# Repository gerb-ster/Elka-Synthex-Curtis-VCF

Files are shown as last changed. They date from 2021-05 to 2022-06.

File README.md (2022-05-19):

# Elka Synthex 'Curtis' VCF

A clone of the VCF found in the Elka Synthex around the CEM 3320 IC. This project is still 'work in progress', a
prototype has been build, but it's not quite bug free. 

_the current design needs to be debugged_

## Status: Work in Progress

- done: first schematic & board design
- done: breadboard and test
- done: design frontpanel
- done: order PCB 
- todo: build (working) prototype

## Links

https://bitbucket.org/XNOTOX/synthex-vcf/src/master/ 
https://electricdruid.net/cem3320-filter-designs/ 
https://www.instructables.com/How-to-Program-an-Attiny85-From-an-Arduino-Uno/

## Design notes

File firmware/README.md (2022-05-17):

# Elka Synthex 'Curtis' VCF firmware

The mode selection is done using a push button and a bunch of ADG412 chips 
and a Atmel ATtiny25/45/85. This directory contains a .ino file with some arduino
code. This needs to be rewritten to proper AVR-C code in a platform.io project.

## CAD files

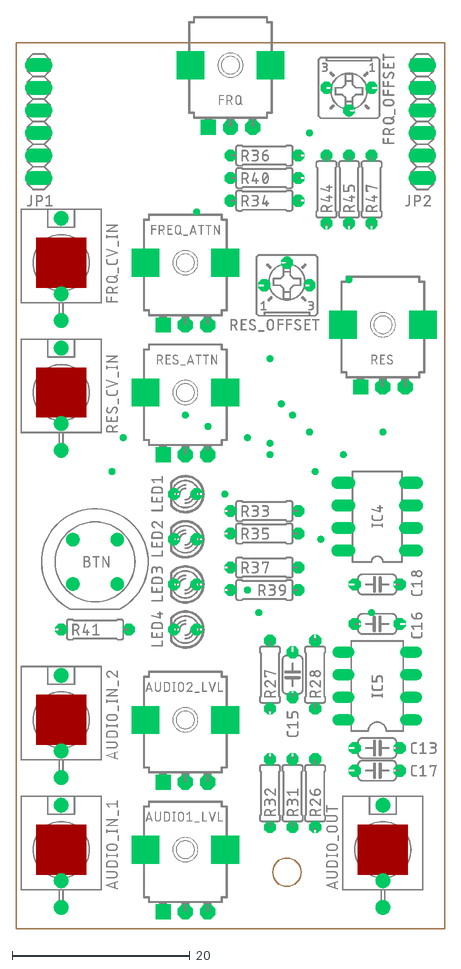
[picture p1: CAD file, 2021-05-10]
faceplates/Elka Synthex Full.dxf
48.3 x 102.7

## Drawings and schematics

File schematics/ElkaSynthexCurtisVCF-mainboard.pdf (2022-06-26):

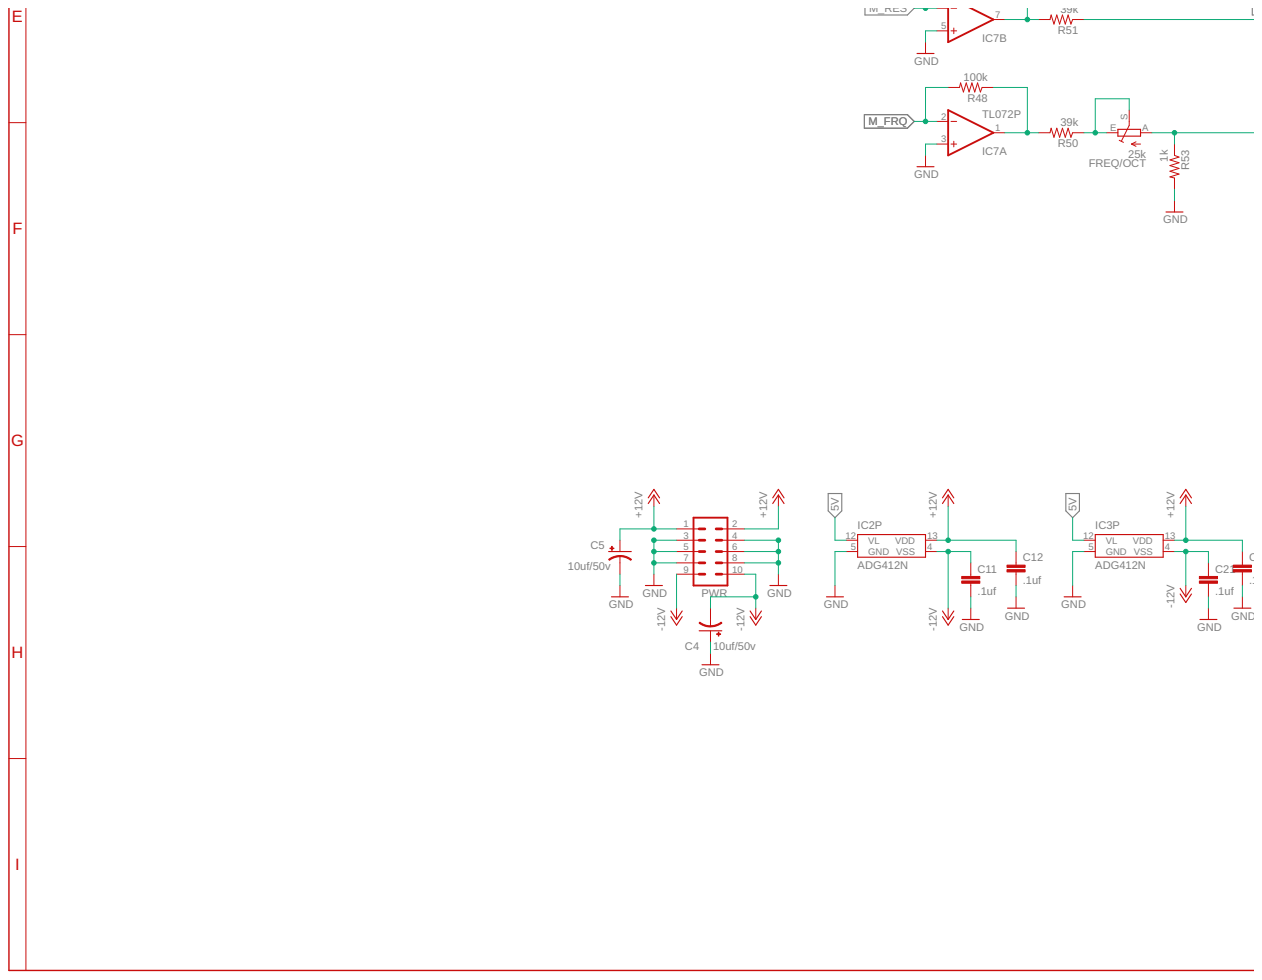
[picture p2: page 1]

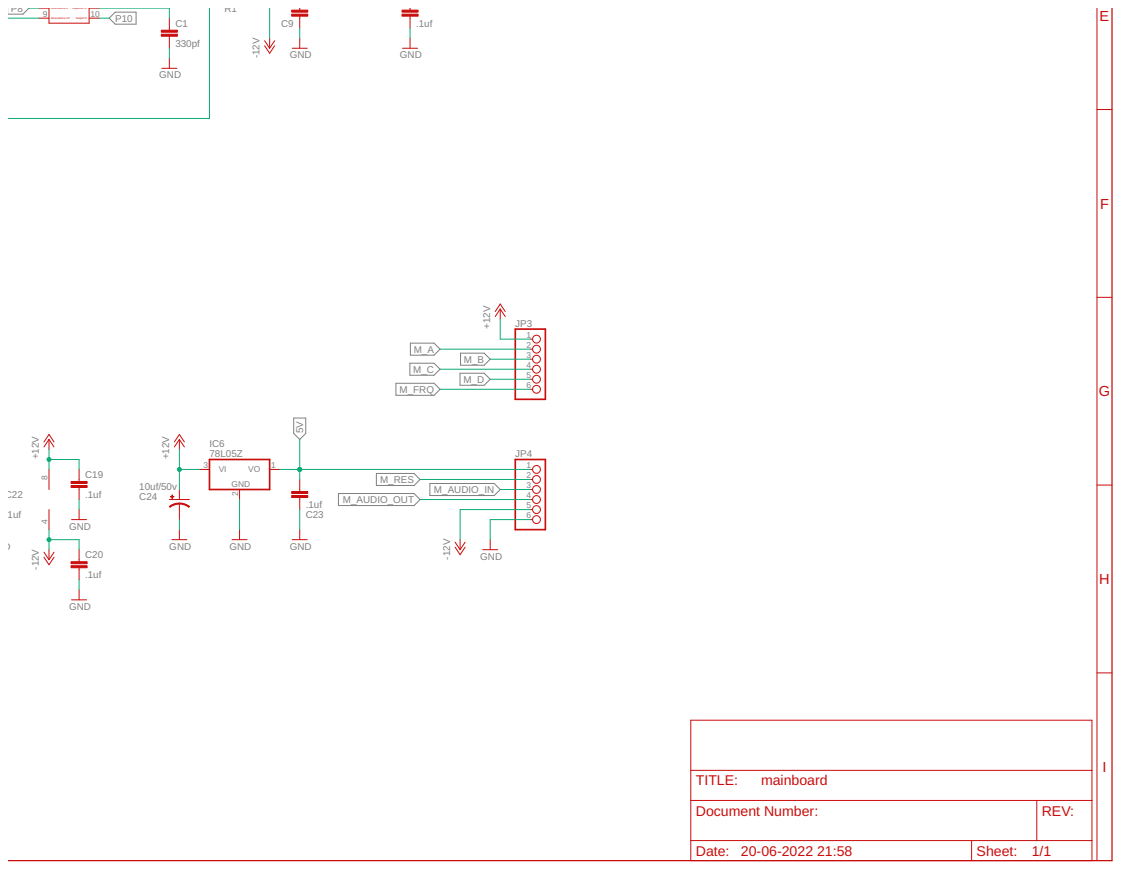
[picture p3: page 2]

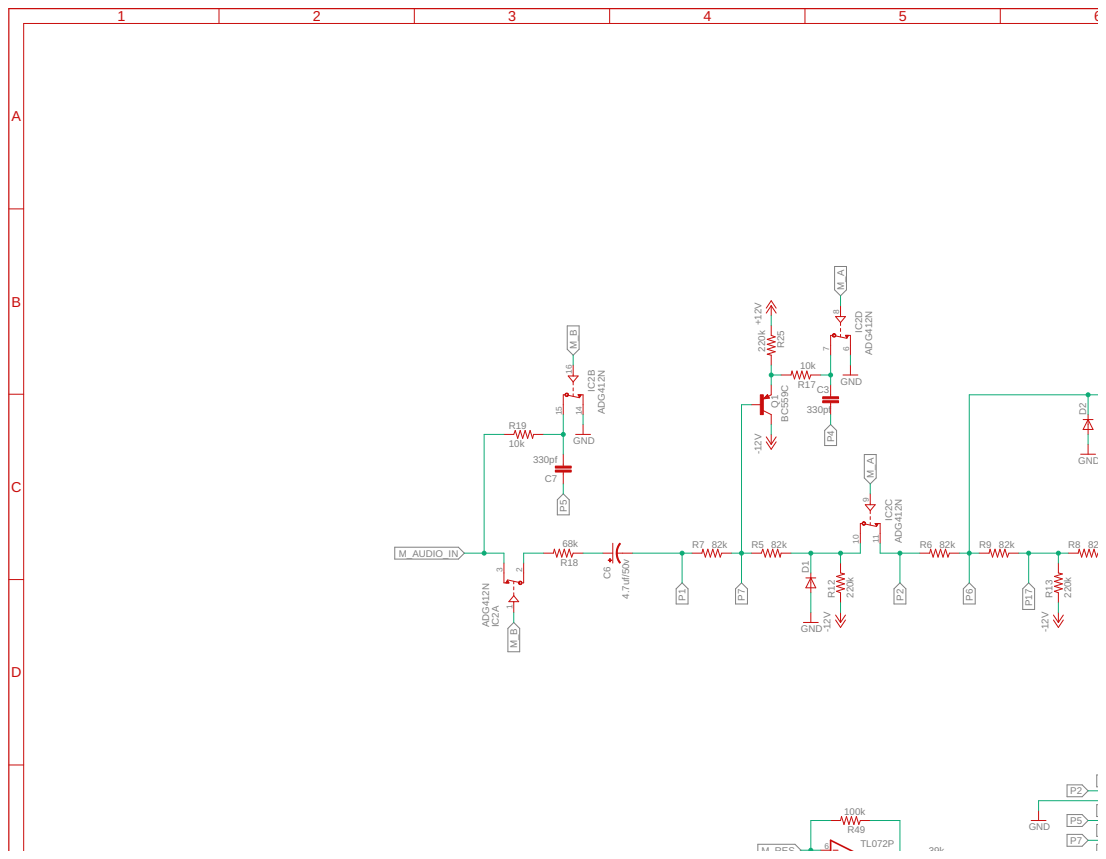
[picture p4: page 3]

+12V -12V 82k 82k 82k 82k 82 220k -12V 220k -12V GND BC559C 10k330pf GND 4.7uf/50v 68k 330pf 10k GND GND 220k GND TL072P 100k 39k ADG412N ADG412N ADG412N ADG412N R7 R5 R6 R9 R8 R12 R13 D1 Q1 R17C3 C6R18 C7 R19 D2 R25 6 R49 1 32 IC2A 16 1415 IC2B 9 1110 IC2C 8 76 IC2D M_RES M_AUDIO_IN M_A M_A M_B M_B P17 P1 P5 P5 P7 P7 P2 P2 P6 P4 ABCD 1 2 3 4 5 6

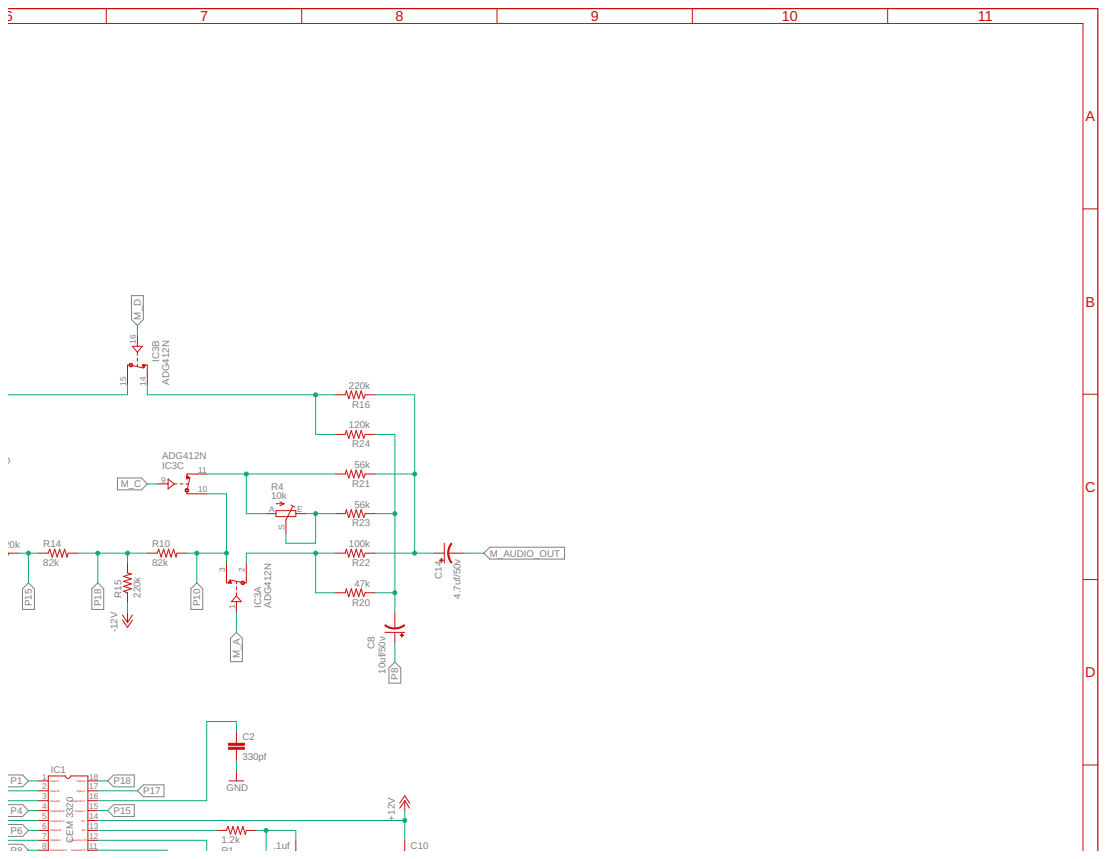
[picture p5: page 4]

+12V -12V 1.2k 330pf GND 10k 82k 82k 82k 82k 820k 82k 220k -12V 220k -12V 82k 220k -12V GND BC559C220k +12V 10k330pf GND 4.7uf/50v 68k f GND 10uf/50v 47k 56k 100k 120k GND 220k 56k .1uf GND 4.7uf/50v CEM 3320 TL072P 100k 39k ADG412N ADG412N ADG412N ADG412N ADG412N ADG412N R1 C2 A E S R4 R7 R5 R6 R9 R8 R10 R12 R13 R14 R15 D1 Q1 R16 R17C3 C6R18 C8 R20 R21 R22 R24 D2 R25 R23 C10 C14 12345678 1112131415161718 IC1 6 R49 16 1415 IC2B 9 1110 IC2C 8 76 IC2D 1 32 IC3A 16 1415 IC3B 9 1110 IC3C M_RES M_C M_D M_AUDIO_OUT M_A M_A M_A M_B P17 P17 P1 P1 P5 P5 P7 P7 P2 P2 P6 P6 P15 P15 P18 P18 P10 P4 P4 P8 P8 Input A Input B Ground Capacitor B Capacitor A Output B Output A Resonance in Capacitor D Frequency ctrl Iee Vcc Output C Capacitor C Input C Input D ABCD 4 5 6 7 8 9 10 11

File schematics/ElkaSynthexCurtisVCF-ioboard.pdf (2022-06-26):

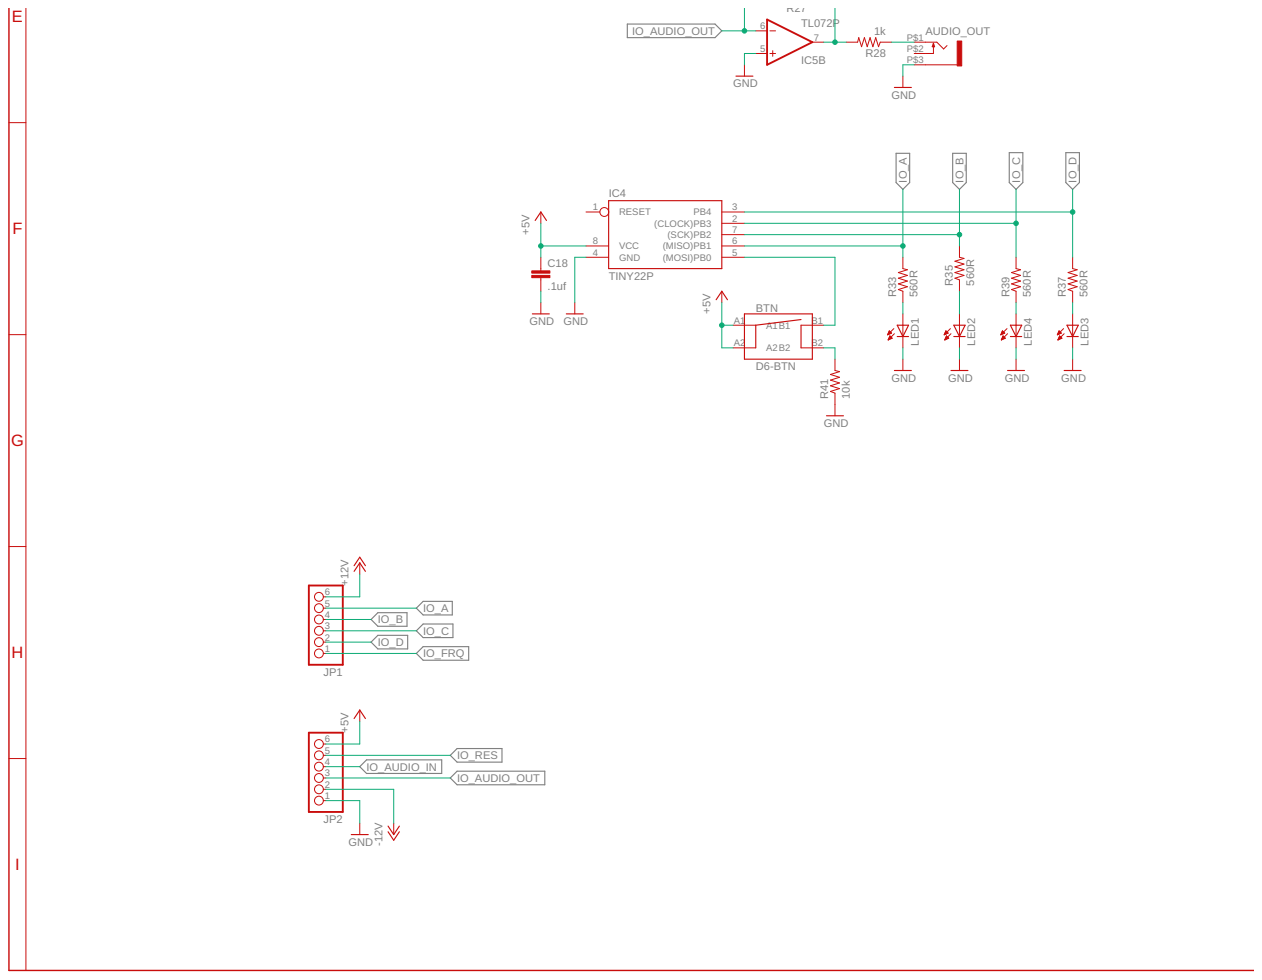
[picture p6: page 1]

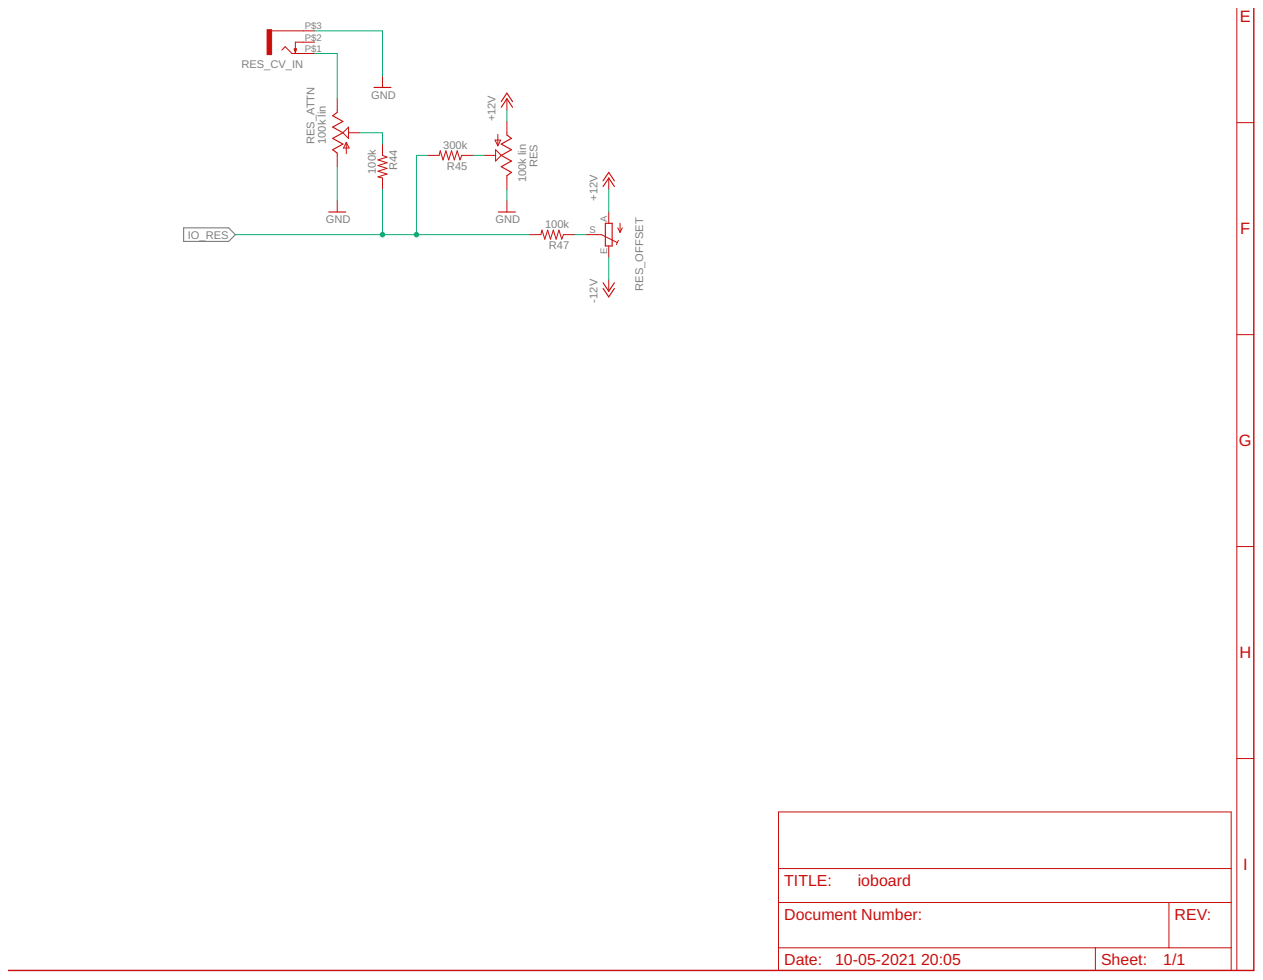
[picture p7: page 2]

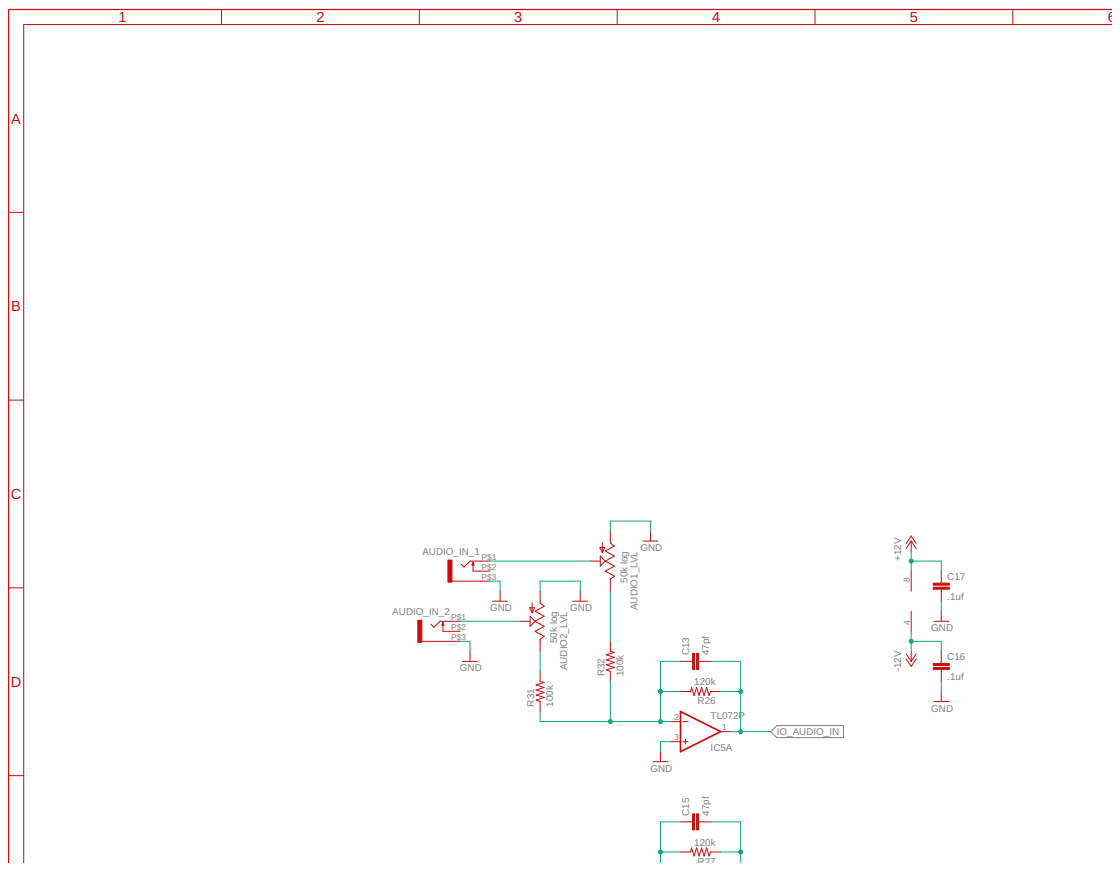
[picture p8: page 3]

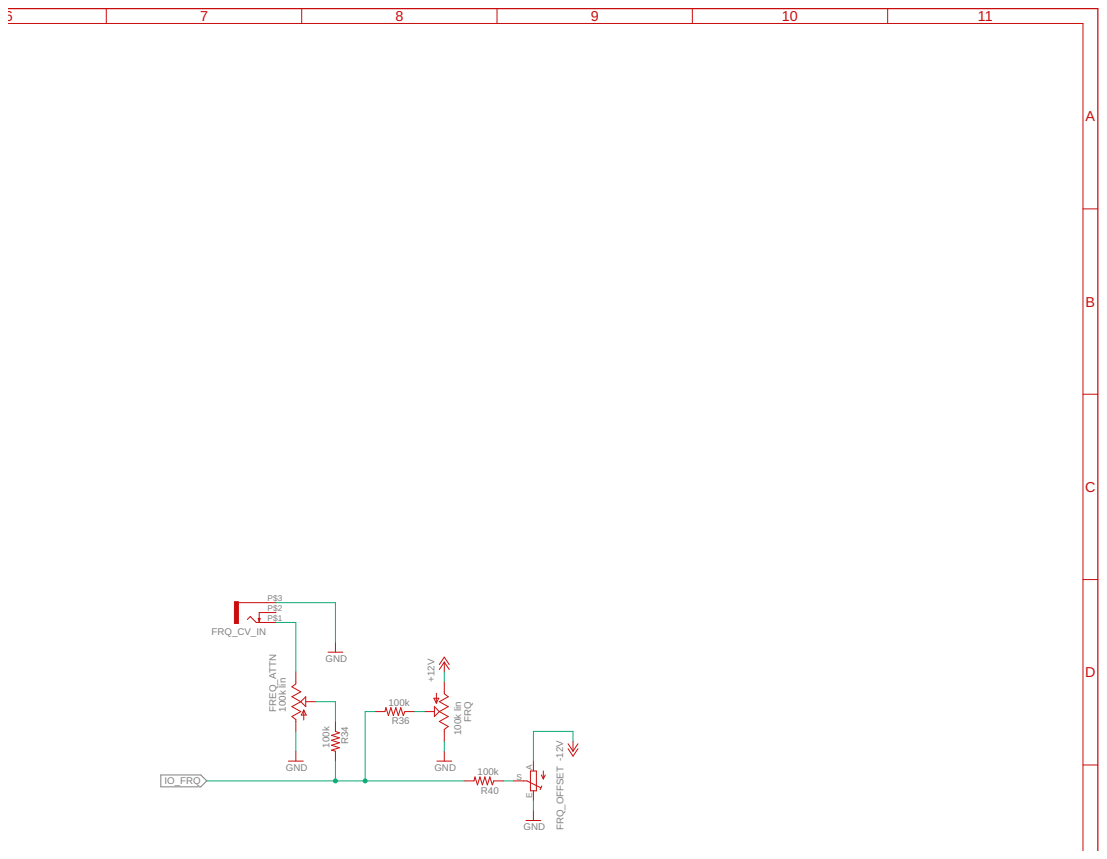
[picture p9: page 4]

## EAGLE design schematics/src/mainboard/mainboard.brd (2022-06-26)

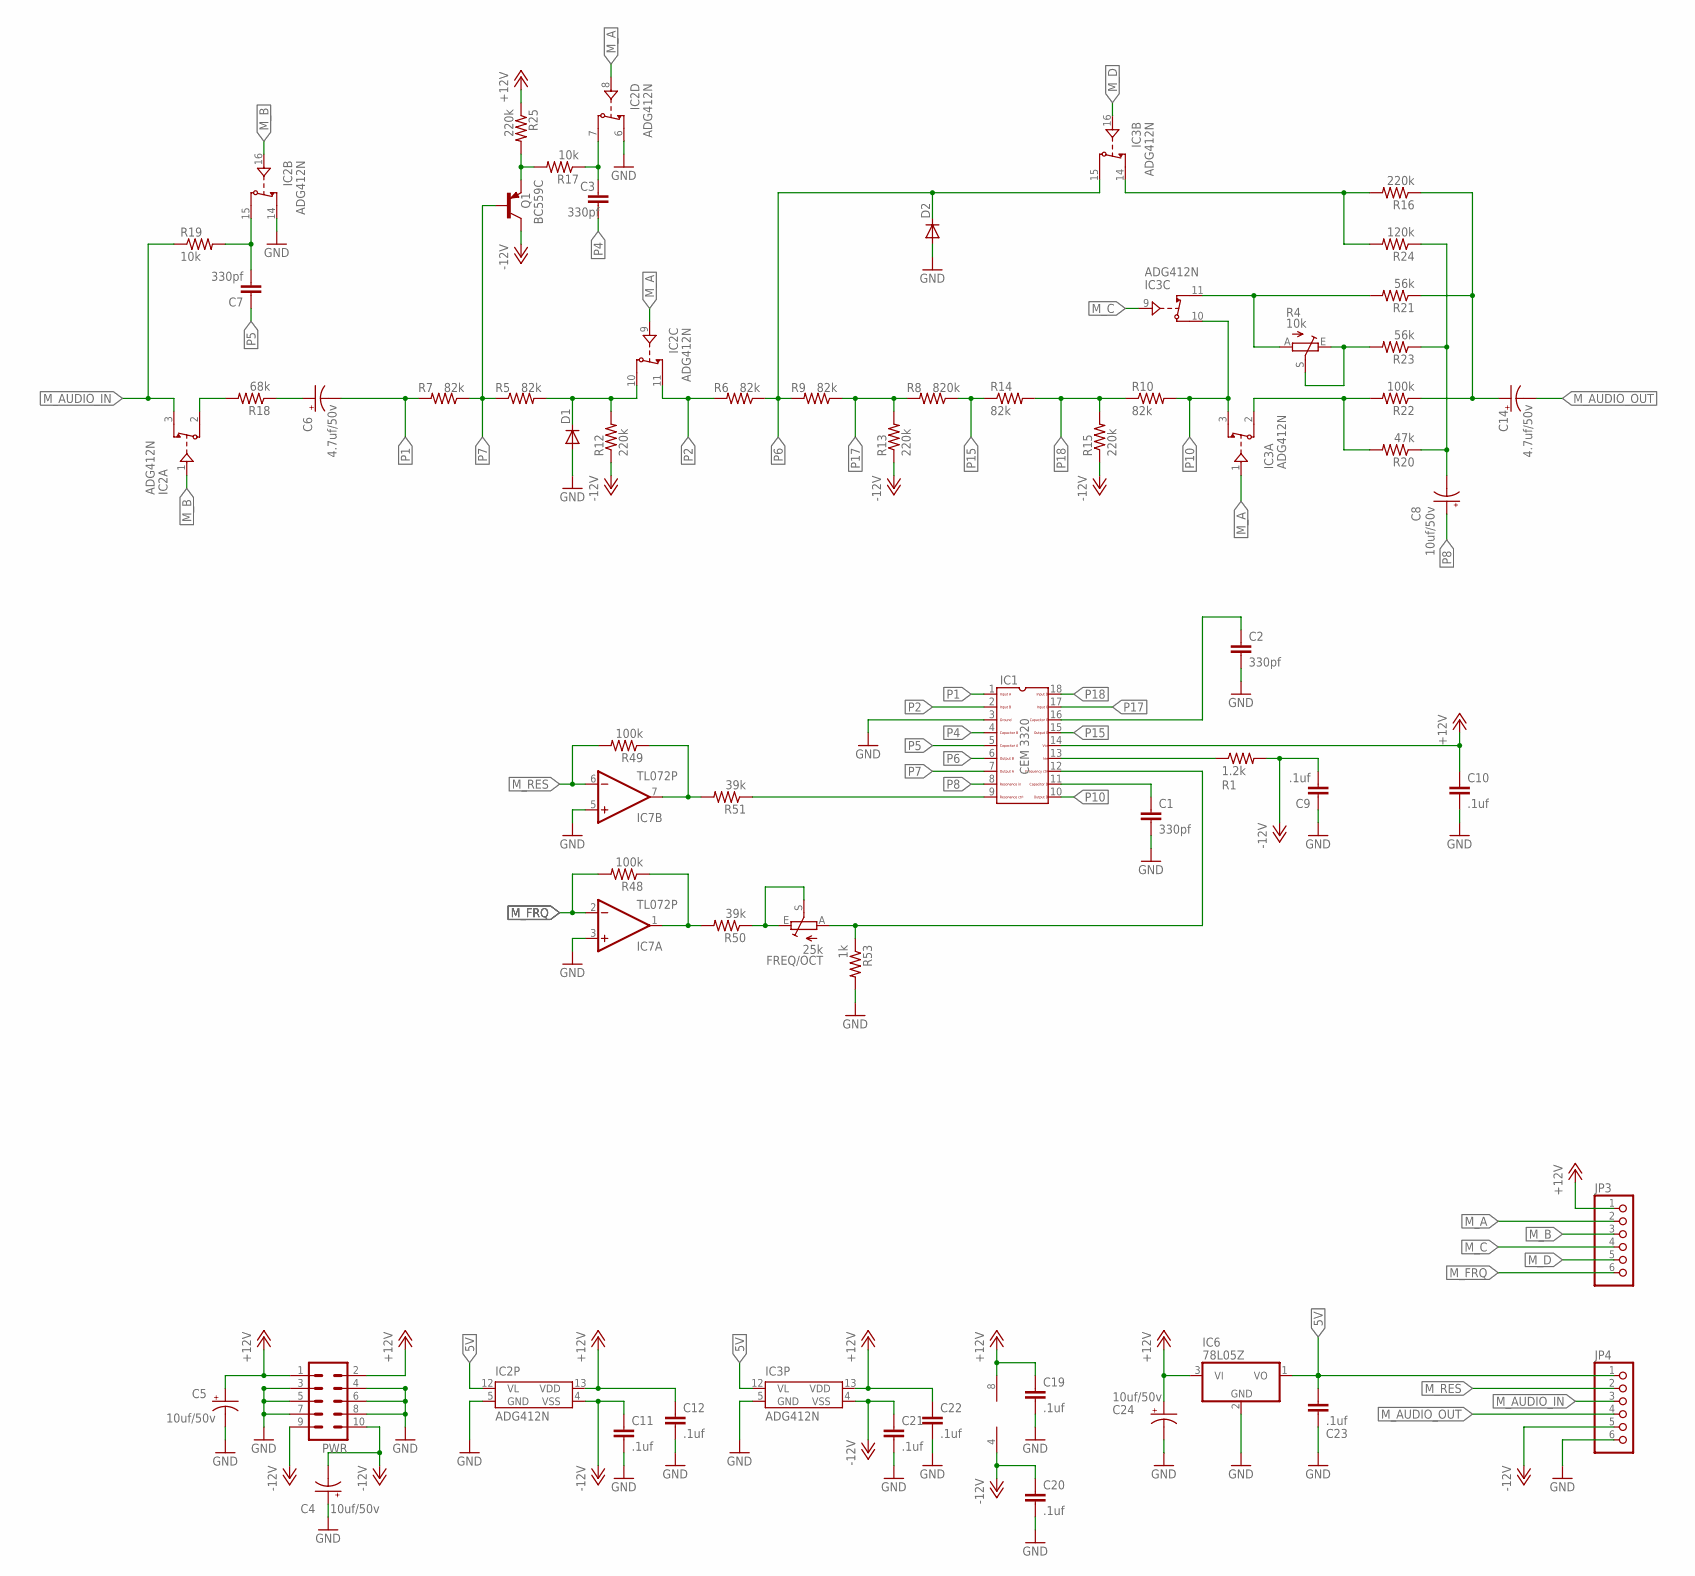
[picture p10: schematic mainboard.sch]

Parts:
C1, C2, C3, C7: 330pf; C050-050X075
C4, C5, C8, C24: 10uf/50v; E2,5-5
C6, C14: 4.7uf/50v; E2,5-5
C9, C10, C11, C12, C19, C20, C21, C22, C23: .1uf; C050-024X044
D1, D2: 1N4148DO35-7; DO35-7
FREQ/OCT: 25k; S64YW
IC1: CEM3320; DIL18
IC2, IC3: ADG412N; DIL16
IC6: 78L05Z; TO92
IC7: TL072P; DIL08
JP3, JP4: PINHD-1X6; 1X06
PWR: ML10
Q1: BC559C; TO92-EBC
R1: 1.2k; 0207/10
R4: 10k; S64YW
R5, R6, R7, R9, R10, R14: 82k; 0207/10
R8: 820k; 0207/10
R12, R13, R15, R16, R25: 220k; 0207/10
R17, R19: 10k; 0207/10
R18: 68k; 0207/10
R20: 47k; 0207/10
R21, R23: 56k; 0207/10
R22, R48, R49: 100k; 0207/10
R24: 120k; 0207/10
R50, R51: 39k; 0207/10
R53: 1k; 0207/10

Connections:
5V: C23.1, IC2.12 (VL), IC3.12 (VL), IC6.1 (VO), JP4.1
+12V: C5.+, C10.1, C12.1, C19.1, C22.1, C24.+, IC1.14, IC2.13 (VDD), IC3.13 (VDD), IC6.3 (VI), IC7.8 (V+), JP3.1, PWR.1, PWR.2, R25.1
-12V: C4.-, C9.2, C11.1, C20.1, C21.1, IC2.4 (VSS), IC3.4 (VSS), IC7.4 (V-), JP4.5, PWR.9, PWR.10, Q1.C, R1.2, R12.1, R13.1, R15.1
GND: C1.1, C2.2, C4.+, C5.-, C9.1, C10.2, C11.2, C12.2, C19.2, C20.2, C21.2, C22.2, C23.2, C24.-, D1.A, D2.A, IC1.3, IC2.5 (GND), IC2.6 (S), IC2.14 (S), IC3.5 (GND), IC6.2 (GND), IC7.3 (+IN), IC7.5 (+IN), JP4.6, PWR.3, PWR.4, PWR.5, PWR.6, PWR.7, PWR.8, R53.2
INT_FRQ: FREQ/OCT.A, IC1.12, R53.1
INT_RES: IC1.9, R51.1
M_A: IC2.8 (IN), IC2.9 (IN), IC3.1 (IN), JP3.2
M_AUDIO_IN: IC2.3 (S), JP4.3, R19.1
M_AUDIO_OUT: C14.-, JP4.4
M_B: IC2.1 (IN), IC2.16 (IN), JP3.3
M_C: IC3.9 (IN), JP3.4
M_D: IC3.16 (IN), JP3.5
M_FRQ: IC7.2 (-IN), JP3.6, R48.2
M_RES: IC7.6 (-IN), JP4.2, R49.2
unnamed: Q1.E, R17.2, R25.2
unnamed: C6.+, R18.1
unnamed: D1.C, IC2.10 (D), R5.2, R12.2
unnamed: IC3.2 (D), R20.2, R22.2
unnamed: IC2.2 (D), R18.2
unnamed: C7.2, IC2.15 (D), R19.2
unnamed: R4.E, R4.S, R23.2
unnamed: C3.1, IC2.7 (D), R17.1
unnamed: C14.+, R16.1, R21.1, R22.1
unnamed: IC3.11 (S), R4.A, R21.2
unnamed: IC3.14 (S), R16.2, R24.2
unnamed: C8.-, R20.1, R23.1, R24.1
unnamed: C2.1, IC1.16
unnamed: IC1.13, R1.1
unnamed: C1.2, IC1.11
unnamed: FREQ/OCT.E, FREQ/OCT.S, R50.1
unnamed: IC7.7 (OUT), R49.1, R51.2
unnamed: IC7.1 (OUT), R48.1, R50.2
P1: C6.-, IC1.1, R7.2
P2: IC1.2, IC2.11 (S), R6.2
P4: C3.2, IC1.4
P5: C7.1, IC1.5
P6: D2.C, IC1.6, IC3.15 (D), R6.1, R9.2
P7: IC1.7, Q1.B, R5.1, R7.1
P8: C8.+, IC1.8
P10: IC1.10, IC3.3 (S), IC3.10 (D), R10.2
P15: IC1.15, R8.1, R14.1
P17: IC1.17, R8.2, R9.1, R13.2
P18: IC1.18, R10.1, R14.2, R15.2

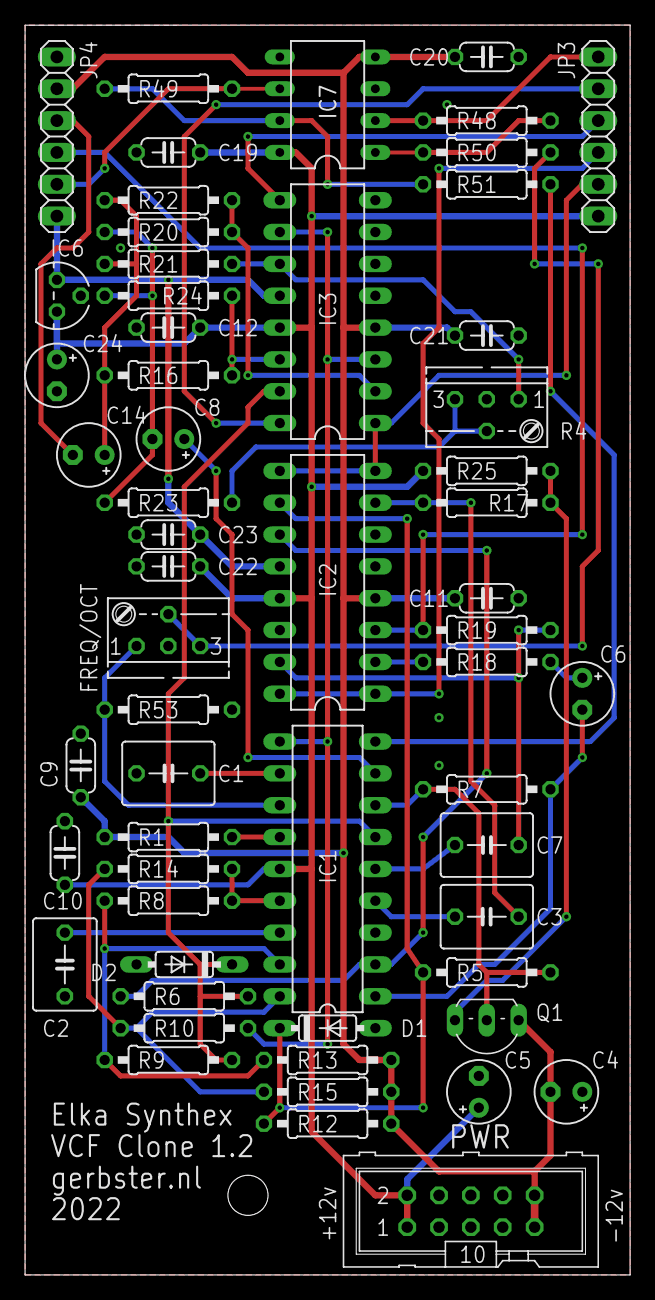
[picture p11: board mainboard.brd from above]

Board: 2 copper layers, 48.3 x 99.7 mm, 58 parts (0 on the bottom side), 43 nets.

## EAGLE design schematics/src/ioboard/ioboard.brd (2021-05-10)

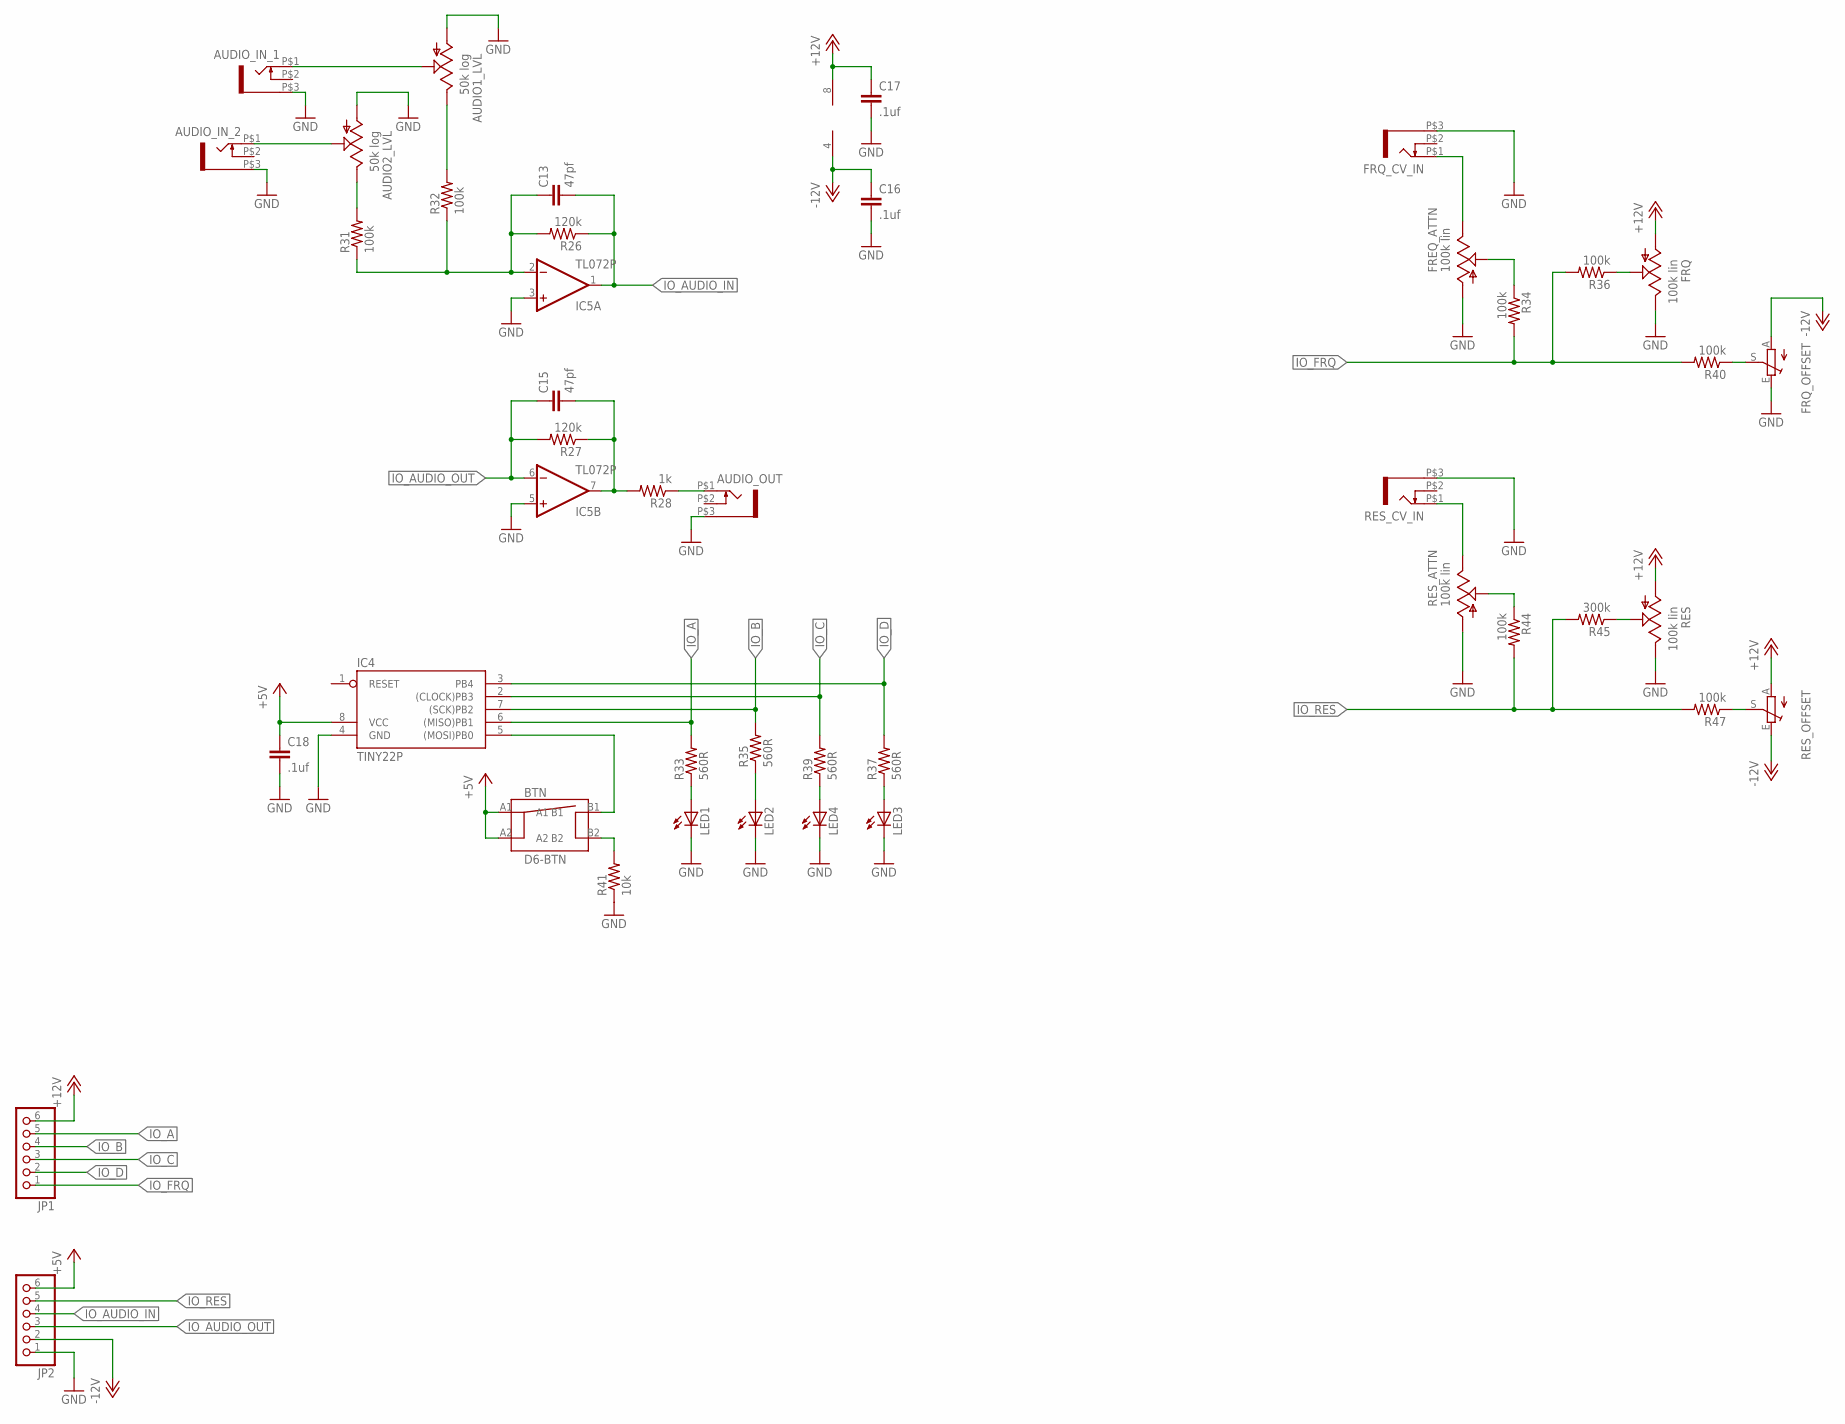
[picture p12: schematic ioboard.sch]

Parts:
AUDIO1_LVL, AUDIO2_LVL: 50k log; EVUF
AUDIO_IN_1, AUDIO_IN_2: WQP-PJ301M-12_JACK
AUDIO_OUT: WQP-PJ301M-12_JACK
BTN: D6-BTN
C13, C15: 47pf; C050-024X044
C16, C17, C18: .1uf; C050-024X044
FREQ_ATTN: 100k lin; EVUF
FRQ: 100k lin; EVUF
FRQ_CV_IN: WQP-PJ301M-12_JACK
FRQ_OFFSET: TRIM_EU-B25P; B25P
IC4: TINY22P; DIL08
IC5: TL072P; DIL08
JP1, JP2: PINHD-1X6; 1X06
LED1, LED2, LED3, LED4: LED3MM
R26, R27: 120k; 0207/7
R28: 1k; 0207/7
R31, R32, R34, R36, R40, R44, R47: 100k; 0207/7
R33, R35, R37, R39: 560R; 0207/7
R41: 10k; 0207/7
R45: 300k; 0207/7
RES: 100k lin; EVUF
RES_ATTN: 100k lin; EVUF
RES_CV_IN: WQP-PJ301M-12_JACK
RES_OFFSET: TRIM_EU-B25P; B25P

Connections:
+5V: BTN.A1, BTN.A2, C18.1, IC4.8 (VCC), JP2.6
+12V: C17.1, FRQ.1 (A), IC5.8 (V+), JP1.6, RES.1 (A), RES_OFFSET.A
-12V: C16.1, FRQ_OFFSET.A, IC5.4 (V-), JP2.2, RES_OFFSET.E
GND: AUDIO1_LVL.1 (A), AUDIO2_LVL.1 (A), AUDIO_IN_1.P$3 (1), AUDIO_IN_2.P$3 (1), AUDIO_OUT.P$3 (1), C16.2, C17.2, C18.2, FREQ_ATTN.1 (A), FRQ.3 (E), FRQ_CV_IN.P$3 (1), FRQ_OFFSET.E, IC4.4 (GND), IC5.3 (+IN), IC5.5 (+IN), JP2.1, LED1.K (C), LED2.K (C), LED3.K (C), LED4.K (C), R41.1, RES.3 (E), RES_ATTN.1 (A), RES_CV_IN.P$3 (1)
IO_A: IC4.6 ((MISO)PB1), JP1.5, R33.2
IO_AUDIO_IN: C13.2, IC5.1 (OUT), JP2.4, R26.1
IO_AUDIO_OUT: C15.1, IC5.6 (-IN), JP2.3, R27.2
IO_B: IC4.7 ((SCK)PB2), JP1.4, R35.2
IO_C: IC4.2 ((CLOCK)PB3), JP1.3, R39.2
IO_D: IC4.3 (PB4), JP1.2, R37.2
IO_FRQ: JP1.1, R34.2, R36.2, R40.2
IO_RES: JP2.5, R44.2, R45.2, R47.2
unnamed: AUDIO_OUT.P$1 (2), R28.1
unnamed: C15.2, IC5.7 (OUT), R27.1, R28.2
unnamed: C13.1, IC5.2 (-IN), R26.2, R31.1, R32.1
unnamed: AUDIO2_LVL.3 (E), R31.2
unnamed: AUDIO1_LVL.3 (E), R32.2
unnamed: AUDIO2_LVL.2 (S), AUDIO_IN_2.P$1 (2)
unnamed: AUDIO1_LVL.2 (S), AUDIO_IN_1.P$1 (2)
unnamed: LED1.A, R33.1
unnamed: FREQ_ATTN.3 (E), FRQ_CV_IN.P$1 (2)
unnamed: FREQ_ATTN.2 (S), R34.1
unnamed: FRQ.2 (S), R36.1
unnamed: FRQ_OFFSET.S, R40.1
unnamed: LED2.A, R35.1
unnamed: RES_ATTN.3 (E), RES_CV_IN.P$1 (2)
unnamed: LED4.A, R39.1
unnamed: BTN.B2, R41.2
unnamed: BTN.B1, IC4.5 ((MOSI)PB0)
unnamed: R44.1, RES_ATTN.2 (S)
unnamed: R45.1, RES.2 (S)
unnamed: LED3.A, R37.1
unnamed: R47.1, RES_OFFSET.S

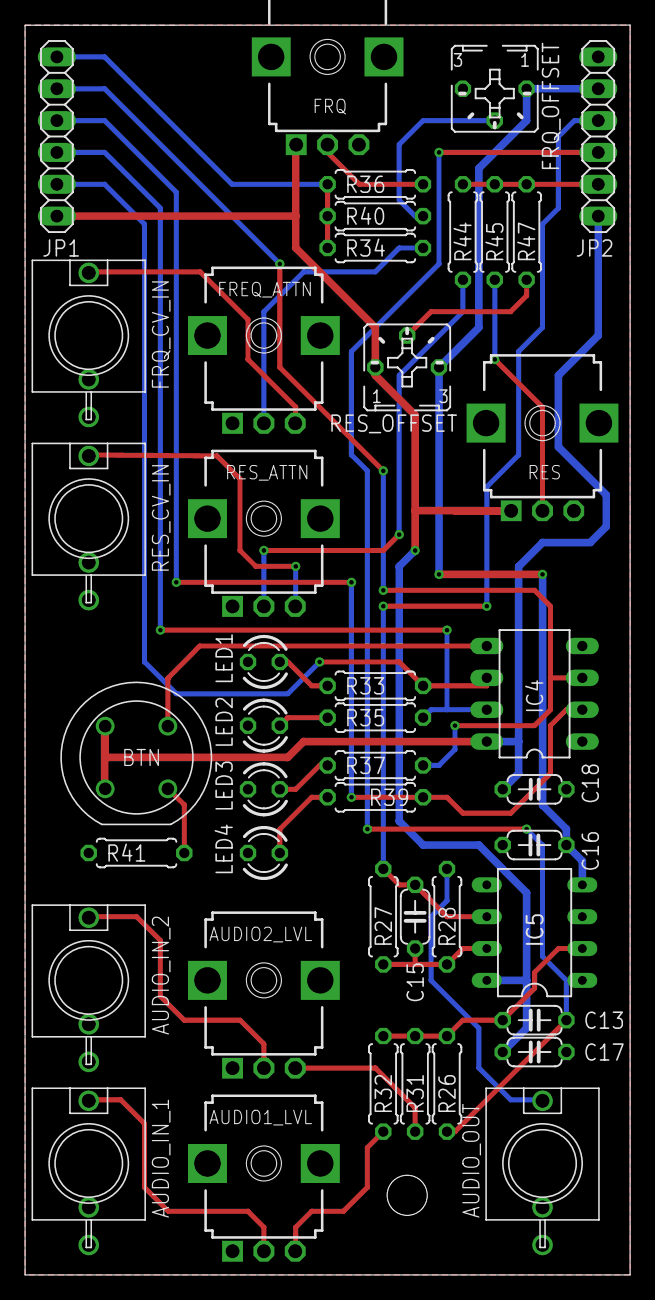
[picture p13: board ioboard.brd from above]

Board: 2 copper layers, 48.3 x 99.7 mm, 43 parts (0 on the bottom side), 33 nets.

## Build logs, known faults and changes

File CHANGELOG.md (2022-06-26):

# Changelog

All notable changes to this project will be documented in this file.

The format is based on [Keep a Changelog](https://keepachangelog.com/en/1.0.0/),
and this project adheres to [Semantic Versioning](https://semver.org/spec/v2.0.0.html).

## [1.0.0] - 2021-10-05

### Added

- Inintial repo setup

## [1.1.0] - 2022-17-05

### Added

- Temporary firmware code

## [1.2.0] - 2022-06-20

### Changed

- Changed filter caps to support larger good quality caps.

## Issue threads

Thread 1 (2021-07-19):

01:Not Working

ijnekenamay, 2021-07-19:
Hi!
I was so interested in this project that I actually fabricated and built a PCB!
But it doesn't work well, somewhere it shorts out and the power supply goes down.

I'm not sure if there was anything wrong with my build method. I am going to start debugging to see if there is a problem somewhere in the schematic.

Keep up the good work!

gerb-ster, 2021-07-19:
Hi there,

Cool! Yeah, the status of that project is still ‘work in progress’.. I’ve build one myself a couple of weeks ago, and although I didn’t had any power issues, I didn’t get all the modes working properly. But then again, I didn’t thoroughly test I yet.

But it shouldn’t have any power issues; most commonly they are caused by either shorted caps/ic, bridged solder joints or op-amps put in the wrong way (I’ve lost quite a few op amp that wat :-)). But you should be able to buzz it out quite easily.

If you need any help, please let me know!

Greetings,

Gerb.

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

ijnekenamay, 2021-07-19:
Thank you for responding!
Is there a specific fix you are aware of for the current PCB?

Thanks.

Closed 2021-08-31.

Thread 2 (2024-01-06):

Reversed Labelling / routing on IO Board

jpa73, 2024-01-06:
Whilst the LED's cycle through correctly from A (LED1)  to D (LED 4) , when checking the corresponding pads of JP1, C & D are reversed. This is likely a routing error on the board.  Noting that LED 3 is used for D on the Schematic.

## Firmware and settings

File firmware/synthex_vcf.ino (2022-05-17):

#define LP 0
#define BP1 1
#define BP2 2
#define HP 3

#define MODE_COUNT 4

#define BTN_PORT 0

#define LP_PORT 1
#define BP1_PORT 2
#define BP2_PORT 4
#define HP_PORT 3

int button_state;
int last_button_state = LOW;

unsigned long last_debounce_time = 0;
unsigned long debounce_delay = 50;

int current_mode = 0;

int enable_mode(int mode)
{
  // set all to low
  digitalWrite(LP_PORT, LOW);
  digitalWrite(BP1_PORT, LOW);
  digitalWrite(BP2_PORT, LOW);
  digitalWrite(HP_PORT, LOW);

  // set selected mode
  switch(mode)
  {
    case LP:
      digitalWrite(LP_PORT, HIGH);
    break;

    case BP1:
      digitalWrite(BP1_PORT, HIGH);
    break;

    case BP2:
      digitalWrite(BP2_PORT, HIGH);
    break;

    case HP:
      digitalWrite(HP_PORT, HIGH);
    break;
  }
}

void setup() 
{
  // button port
  pinMode(BTN_PORT, INPUT);

  // output port
  pinMode(LP_PORT, OUTPUT);
  pinMode(BP1_PORT, OUTPUT);
  pinMode(BP2_PORT, OUTPUT);
  pinMode(HP_PORT, OUTPUT);

  // start
  enable_mode(current_mode);
}

void loop() 
{
  int reading = digitalRead(BTN_PORT);

  if (reading != last_button_state)
  {
    last_debounce_time = millis();
  }
  
  if ((millis() - last_debounce_time) > debounce_delay) 
  {
    if (reading != button_state)
    {
      button_state = reading;

      if (button_state == HIGH) 
      {
        current_mode++;

        if(current_mode == MODE_COUNT)
        {
          current_mode = 0;
        }
        
        enable_mode(current_mode);
      }
    }
  }

  last_button_state = reading;
}

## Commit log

2021-05-10 Added files & structure
    [Elka Synthex Full.dxf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]
2021-08-06 Updated some schematics and docs
    [ElkaSynthexCurtisVCF-ioboard.GBL, ElkaSynthexCurtisVCF-ioboard.GBO, ElkaSynthexCurtisVCF-ioboard.GBP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]
2021-08-10 Fixed some bugs and updated documentation
    [ElkaSynthexCurtisVCF-ioboard.XLN, ElkaSynthexCurtisVCF-mainboard.XLN, gerber_job.gbrjob]
2022-04-20 Some updates & bugfixes
    [ElkaSynthexCurtisVCF-ioboard.XLN, ElkaSynthexCurtisVCF-mainboard.XLN, gerber_job.gbrjob]
2022-04-22 Fixed schematics & descriptions
    [ElkaSynthexCurtisVCF-ioboard.XLN, ElkaSynthexCurtisVCF-mainboard.XLN, gerber_job.gbrjob]
2022-05-17 Updated Firmware
    [ElkaSynthexCurtisVCF-ioboard.XLN, ElkaSynthexCurtisVCF-mainboard.XLN, gerber_job.gbrjob]
2022-05-18 Updated Faceplates
    [ElkaSynthexCurtisVCF-ioboard.XLN, ElkaSynthexCurtisVCF-mainboard.XLN, gerber_job.gbrjob]
2022-05-18 Fixed issues
    [ElkaSynthexCurtisVCF-ioboard.XLN, ElkaSynthexCurtisVCF-mainboard.XLN, gerber_job.gbrjob]
2022-05-21 Fixed schematics
    [ElkaSynthexCurtisVCF-ioboard.XLN, ElkaSynthexCurtisVCF-mainboard.XLN, gerber_job.gbrjob]
2022-05-28 General updates
    [ElkaSynthexCurtisVCF-ioboard.GKO, ElkaSynthexCurtisVCF-mainboard.GKO, copper_bottom.gbr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]
2022-06-26 Faceplates & Bugfixes
    [mainboard.brd, mainboard.sch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]
